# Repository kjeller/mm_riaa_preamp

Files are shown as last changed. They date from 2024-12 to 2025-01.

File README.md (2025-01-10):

# RIAA Preamp (MM)

Colorful PCB layout

* Electrical schematic based on [Elliot's design](https://sound-au.com/project06.htm)

* The PCB layout is based on my friend's power supply layout - Hi David :)

Note: It has been tested both with +/-15 and +/-9V supply. 15V fed through the regulators and 2*9V feed from batteries, skipping the power supply.

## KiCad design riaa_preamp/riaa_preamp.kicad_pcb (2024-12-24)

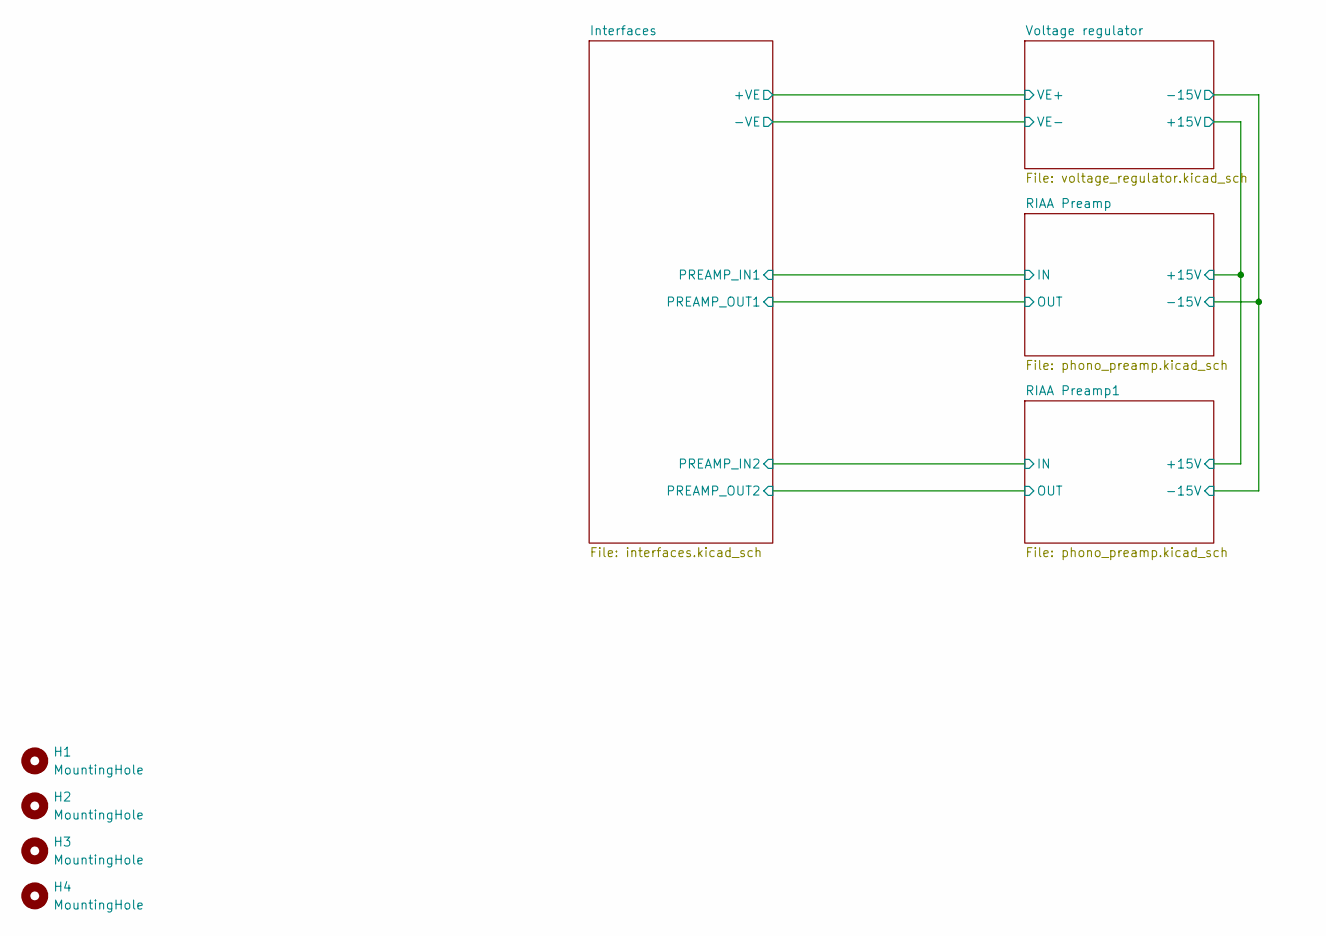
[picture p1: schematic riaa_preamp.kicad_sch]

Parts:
H1, H2, H3, H4: MountingHole; MountingHole_4.3mm_M4_DIN965

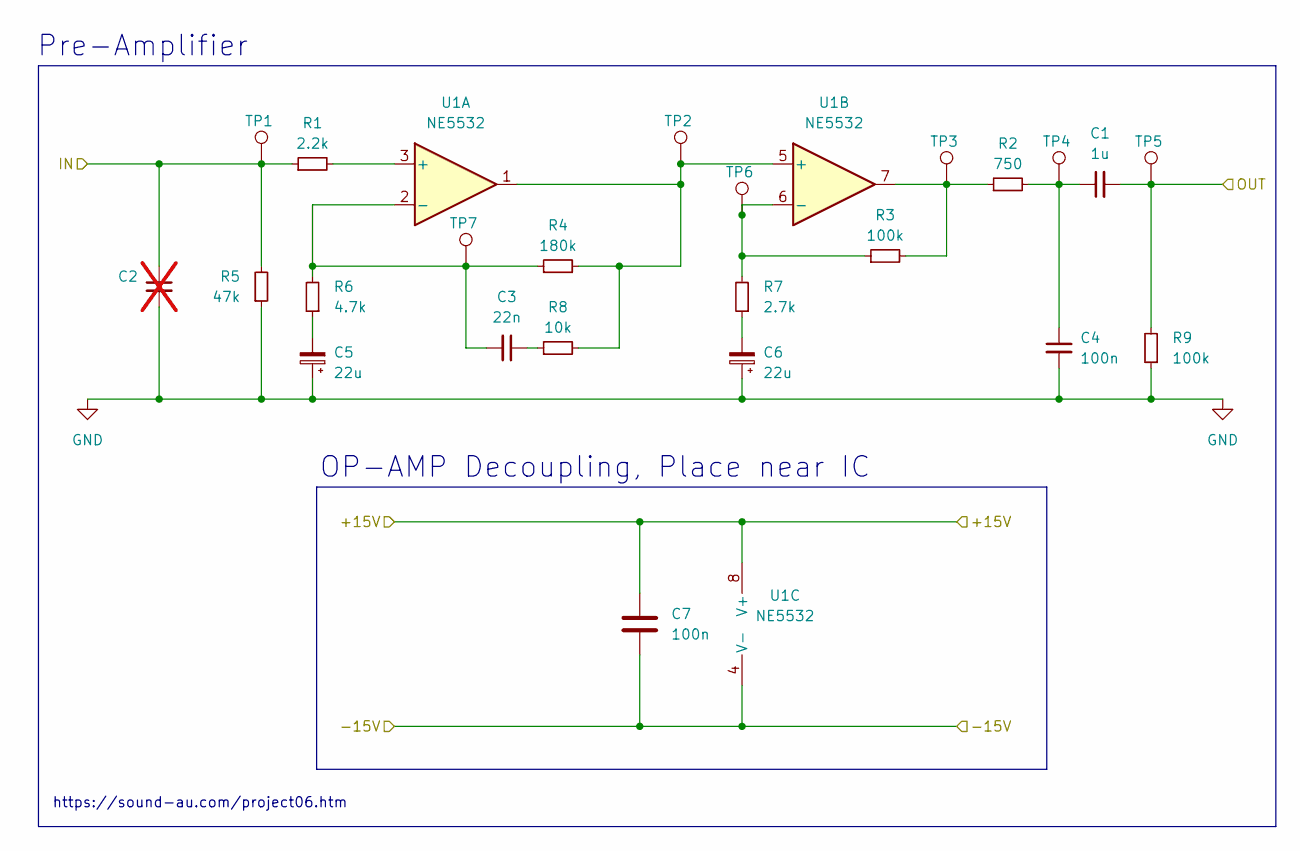
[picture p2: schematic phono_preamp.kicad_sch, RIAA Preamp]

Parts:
C1: 1u; C_0603_1608Metric_Pad1.08x0.95mm_HandSolder
C2: C_0603_1608Metric_Pad1.08x0.95mm_HandSolder; not fitted
C3: 22n; C_0603_1608Metric_Pad1.08x0.95mm_HandSolder
C4: 100n; C_0603_1608Metric_Pad1.08x0.95mm_HandSolder
C5, C6: 22u; CP_Radial_D5.0mm_P2.00mm
C7: 100n; C_0603_1608Metric_Pad1.08x0.95mm_HandSolder; Manufacturer Part Numbe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 CL10B104KB8NNNC; JLC C1591
R1: 2.2k; R_0603_1608Metric_Pad0.98x0.95mm_HandSolder
R2: 750; R_0603_1608Metric_Pad0.98x0.95mm_HandSolder
R3, R9: 100k; R_0603_1608Metric_Pad0.98x0.95mm_HandSolder
R4: 180k; R_0603_1608Metric_Pad0.98x0.95mm_HandSolder
R5: 47k; R_0603_1608Metric_Pad0.98x0.95mm_HandSolder
R6: 4.7k; R_0603_1608Metric_Pad0.98x0.95mm_HandSolder
R7: 2.7k; R_0603_1608Metric_Pad0.98x0.95mm_HandSolder
R8: 10k; R_0603_1608Metric_Pad0.98x0.95mm_HandSolder
TP1, TP2, TP3, TP4, TP5, TP6, TP7: TestPoint; TestPoint_THTPad_1.0x1.0mm_Drill0.5mm
U1: NE5532; SOIC-8_3.9x4.9mm_P1.27mm

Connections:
/Interfaces/PREAMP_IN1: C2.1, R1.1, R5.2, TP1.1; also elsewhere on the board
/Interfaces/PREAMP_OUT1: C1.2, R9.2, TP5.1; also elsewhere on the board
/RIAA Preamp/+15V: C7.2, U1.8 (V+); also elsewhere on the board
/RIAA Preamp/-15V: C7.1, U1.4 (V-); also elsewhere on the board
GND: C2.2, C4.2, C5.1, C6.1, R5.1, R9.1; also elsewhere on the board
unnamed: C1.1, C4.1, R2.2, TP4.1
unnamed: C3.1, R8.1
unnamed: C5.2, R6.1
unnamed: C6.2, R7.1
unnamed: R2.1, R3.2, TP3.1, U1.7
unnamed: R1.2, U1.3 (+)
unnamed: C3.2, R4.1, R6.2, TP7.1, U1.2 (-)
unnamed: R4.2, R8.2, TP2.1, U1.1, U1.5 (+)
unnamed: R3.1, R7.2, TP6.1, U1.6 (-)

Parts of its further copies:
C8: 1u; C_0603_1608Metric_Pad1.08x0.95mm_HandSolder
C9: C_0603_1608Metric_Pad1.08x0.95mm_HandSolder; not fitted
C10: 22n; C_0603_1608Metric_Pad1.08x0.95mm_HandSolder
C11: 100n; C_0603_1608Metric_Pad1.08x0.95mm_HandSolder
C12, C13: 22u; CP_Radial_D5.0mm_P2.00mm
C14: 100n; C_0603_1608Metric_Pad1.08x0.95mm_HandSolder; Manufacturer Part Numbe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 CL10B104KB8NNNC; JLC C1591
R10: 2.2k; R_0603_1608Metric_Pad0.98x0.95mm_HandSolder
R11: 750; R_0603_1608Metric_Pad0.98x0.95mm_HandSolder
R12, R18: 100k; R_0603_1608Metric_Pad0.98x0.95mm_HandSolder
R13: 180k; R_0603_1608Metric_Pad0.98x0.95mm_HandSolder
R14: 47k; R_0603_1608Metric_Pad0.98x0.95mm_HandSolder
R15: 4.7k; R_0603_1608Metric_Pad0.98x0.95mm_HandSolder
R16: 2.7k; R_0603_1608Metric_Pad0.98x0.95mm_HandSolder
R17: 10k; R_0603_1608Metric_Pad0.98x0.95mm_HandSolder
TP8, TP9, TP10, TP11, TP12, TP13, TP14: TestPoint; TestPoint_THTPad_1.0x1.0mm_Drill0.5mm
U2: NE5532; SOIC-8_3.9x4.9mm_P1.27mm

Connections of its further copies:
/Interfaces/PREAMP_IN2: C9.1, R10.1, R14.2, TP8.1; also elsewhere on the board
/Interfaces/PREAMP_OUT2: C8.2, R18.2, TP12.1; also elsewhere on the board
/RIAA Preamp/+15V: C14.2, U2.8 (V+); also elsewhere on the board
/RIAA Preamp/-15V: C14.1, U2.4 (V-); also elsewhere on the board
GND: C9.2, C11.2, C12.1, C13.1, R14.1, R18.1; also elsewhere on the board
unnamed: C10.1, R17.1
unnamed: C8.1, C11.1, R11.2, TP11.1
unnamed: C12.2, R15.1
unnamed: C13.2, R16.1
unnamed: R11.1, R12.2, TP10.1, U2.7
unnamed: R10.2, U2.3 (+)
unnamed: C10.2, R13.1, R15.2, TP14.1, U2.2 (-)
unnamed: R13.2, R17.2, TP9.1, U2.1, U2.5 (+)
unnamed: R12.1, R16.2, TP13.1, U2.6 (-)

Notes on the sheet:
Pre-Amplifier
https://sound-au.com/project06.htm
OP-AMP Decoupling, Place near IC

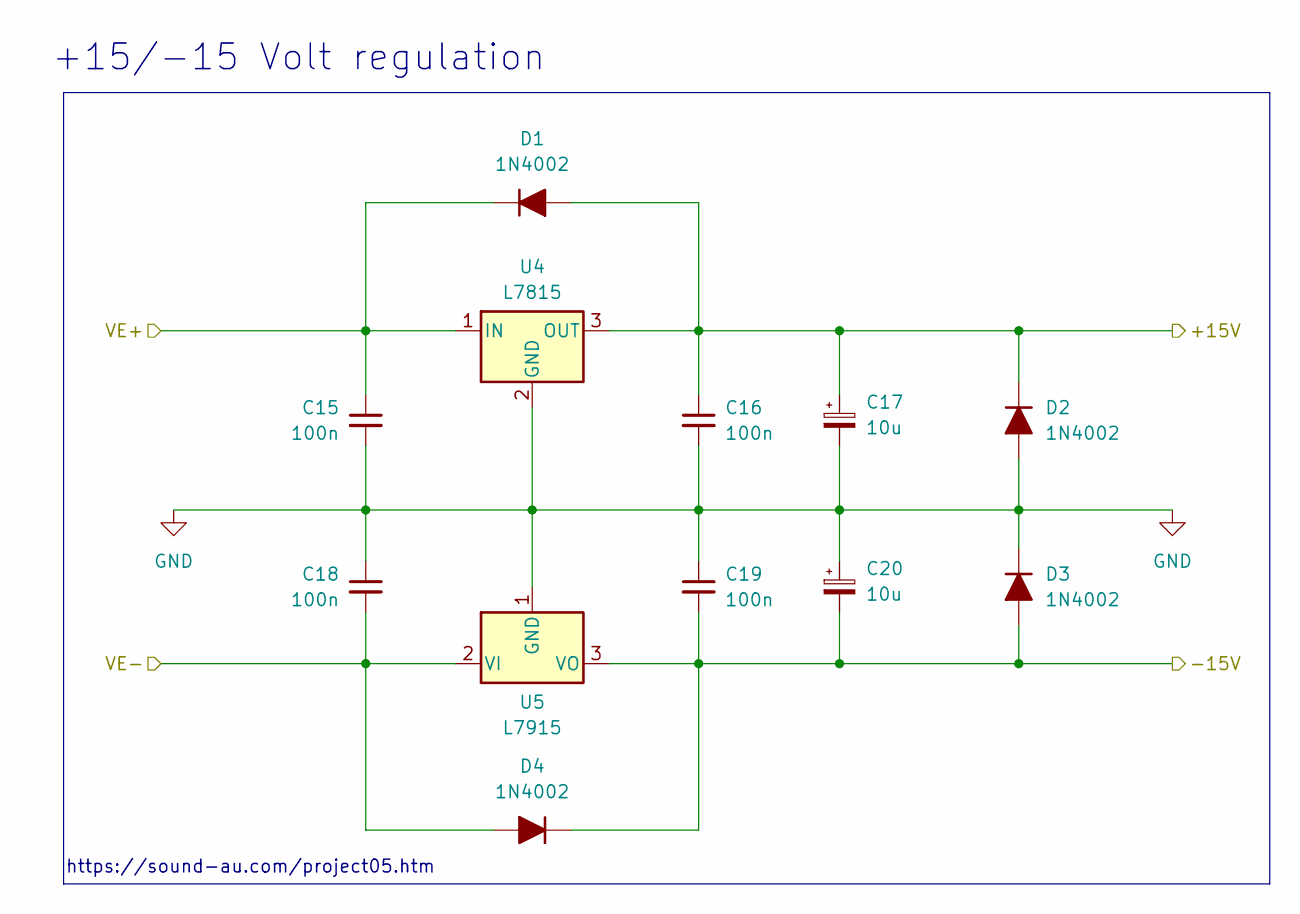
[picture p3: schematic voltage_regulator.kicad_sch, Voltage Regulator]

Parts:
C15, C16, C18, C19: 100n; C_0603_1608Metric_Pad1.08x0.95mm_HandSolder
C17, C20: 10u; CP_Radial_D5.0mm_P2.00mm
D1, D2, D3, D4: 1N4002; D_SOD-123F
U4: L7815; TO-220-3_Horizontal_TabUp
U5: L7915; TO-220-3_Horizontal_TabUp

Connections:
/Interfaces/+VE: C15.1, D1.1 (K), U4.1 (IN); also elsewhere on the board
/Interfaces/-VE: C18.2, D4.2 (A), U5.2 (VI); also elsewhere on the board
/RIAA Preamp/+15V: C16.1, C17.1, D1.2 (A), D2.1 (K), U4.3 (OUT); also elsewhere on the board
/RIAA Preamp/-15V: C19.2, C20.2, D3.2 (A), D4.1 (K), U5.3 (VO); also elsewhere on the board
GND: C15.2, C16.2, C17.2, C18.1, C19.1, C20.1, D2.2 (A), D3.1 (K), U4.2 (GND), U5.1 (GND); also elsewhere on the board

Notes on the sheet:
+15/-15 Volt regulation
https://sound-au.com/project05.htm

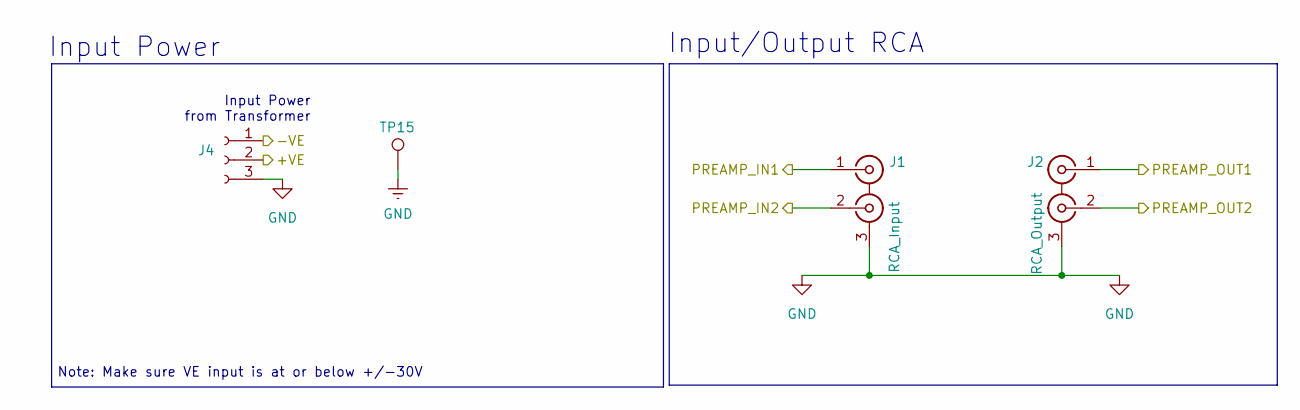
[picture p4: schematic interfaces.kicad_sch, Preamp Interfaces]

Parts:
J1: RCA_Input; RCJ-01_Stereo
J2: RCA_Output; RCJ-01_Stereo
J4: Conn_01x03_Socket; JST_EH_B3B-EH-A_1x03_P2.50mm_Vertical
TP15: TestPoint; TestPoint_THTPad_1.0x1.0mm_Drill0.5mm

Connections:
/Interfaces/+VE: J4.2; also elsewhere on the board
/Interfaces/-VE: J4.1; also elsewhere on the board
/Interfaces/PREAMP_IN1: J1.1 (IN1); also elsewhere on the board
/Interfaces/PREAMP_IN2: J1.2 (IN2); also elsewhere on the board
/Interfaces/PREAMP_OUT1: J2.1 (IN1); also elsewhere on the board
/Interfaces/PREAMP_OUT2: J2.2 (IN2); also elsewhere on the board
GND: J1.3 (EXT), J2.3 (EXT), J4.3, TP15.1; also elsewhere on the board

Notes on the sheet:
Input Power
Input Power from Transformer
Note: Make sure VE input is at or below +/-30V
Input/Output RCA

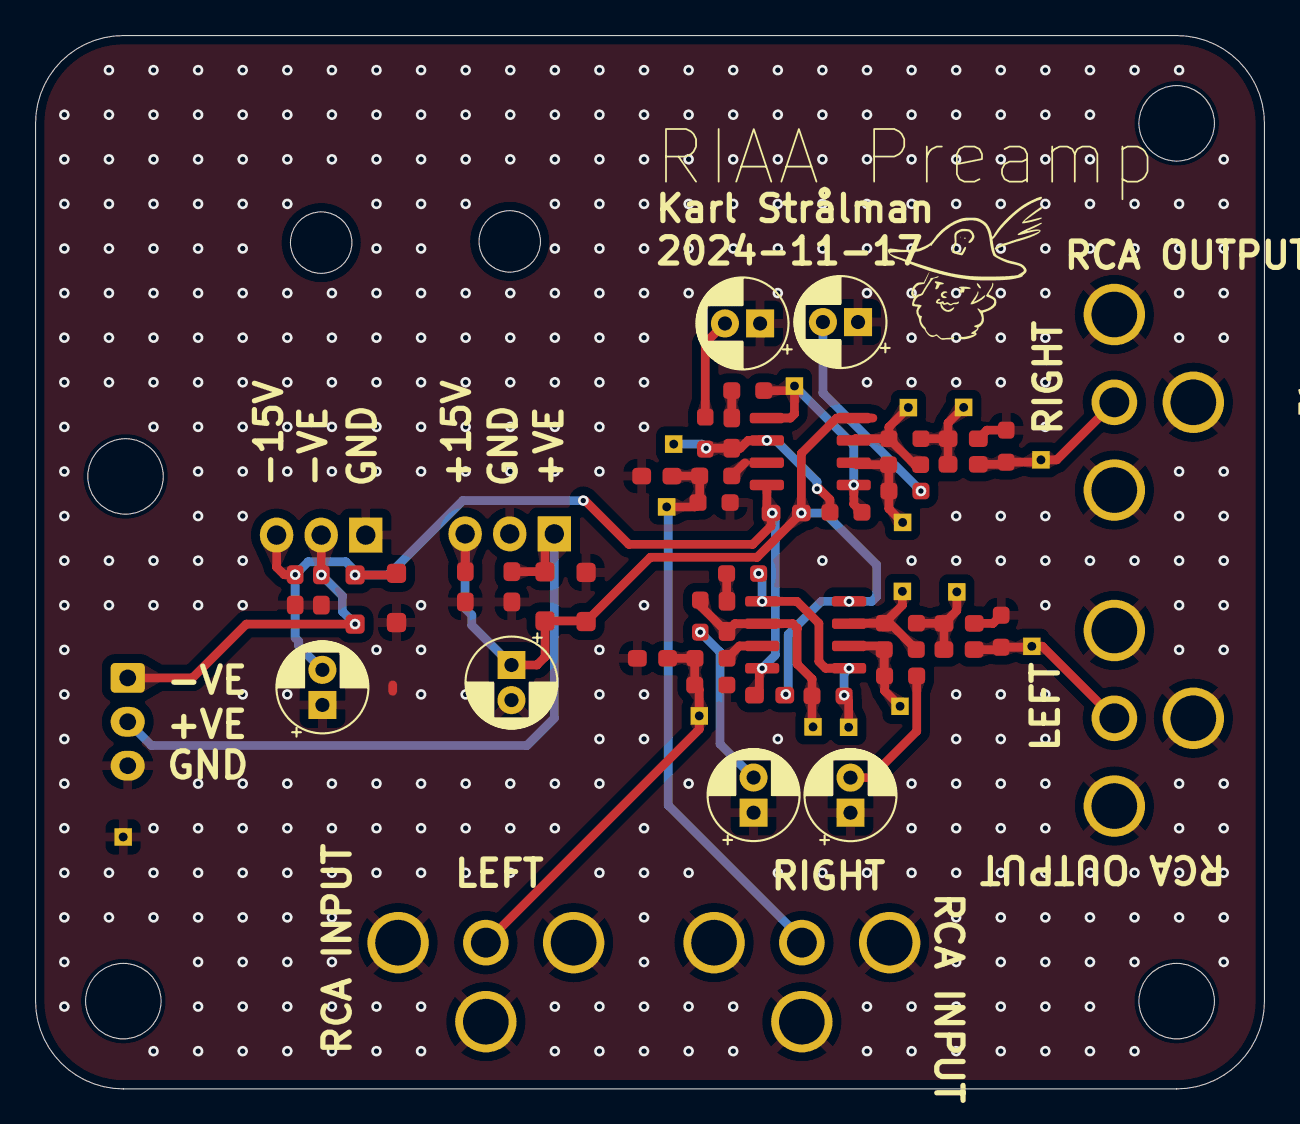
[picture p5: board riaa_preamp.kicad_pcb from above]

Board: 2 copper layers, 70.0 x 60.0 mm, 68 parts (0 on the bottom side), 27 nets.
